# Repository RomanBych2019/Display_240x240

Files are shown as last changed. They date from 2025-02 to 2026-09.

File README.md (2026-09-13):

# Display 240x240

Прошивка дисплея 240x240 для системы CNG/EVO на базе ESP32-C3. Устройство читает данные автомобиля и газового блока по CAN, отображает телеметрию на TFT-дисплее, рассчитывает показатели экономичного вождения и поднимает локальный Wi-Fi веб-портал для просмотра параметров, настройки страниц дисплея, загрузки файлов и OTA-обновления.

## Возможности

- Прием CAN-данных EVO и J1939: обороты, скорость, пробег, расход ДТ, температуры, нагрузка двигателя, вес автомобиля, параметры CNG.
- Отображение страниц на круглом/квадратном TFT 240x240: CNG, параметры EVO, кнопка газ/ДТ, уровень топлива, соленоиды, потеря связи с EVO.
- Переключение пользовательских страниц жестами тач-контроллера CST816D.
- Долгое нажатие на странице кнопки газ/ДТ отправляет CAN-команду включения/выключения газа.
- Расчет уровня экономичного вождения по карте `ACC/RPM`.
- Расчет среднего расхода газа и примерного остаточного пробега.
- Веб-портал в режиме Wi-Fi AP для телеметрии и настроек.
- OTA-обновление через GyverPortal.
- Контроль перегрева ESP32: при высокой температуре снижается мощность Wi-Fi, частота обновления и яркость дисплея.

## Аппаратная платформа

- MCU: `ESP32-C3 DevKitM-1`
- Framework: Arduino
- Дисплей: TFT 240x240, драйвер `GC9A01`, библиотека `TFT_eSPI`
- Тач-контроллер: `CST816D`
- CAN: TWAI ESP32-C3, библиотека `ESP32-TWAI-CAN`
- Файловая система: `LittleFS`

### Основные пины

| Узел | Сигнал | GPIO |
| --- | --- | --- |
| CAN | RX | `GPIO20` |
| CAN | TX | `GPIO21` |
| Touch I2C | SDA | `GPIO4` |
| Touch I2C | SCL | `GPIO5` |
| Touch | INT | `GPIO0` |
| Touch | RST | `GPIO1` |
| TFT SPI | MOSI | `GPIO7` |
| TFT SPI | SCLK | `GPIO6` |
| TFT | CS | `GPIO10` |
| TFT | DC | `GPIO2` |
| TFT | BL | `GPIO3` |
| TFT | RST | `-1` |

Пины TFT задаются в локальной копии библиотеки: `lib/TFT_eSPI-master/User_Setup.h`.

## Сборка и прошивка

Проект собирается через PlatformIO.

```bash
pio run
```

Загрузка прошивки:

```bash
pio run --target upload
```

Загрузка файлов LittleFS из папки `data/`:

```bash
pio run --target uploadfs
```

Монитор порта:

```bash
pio device monitor
```

Основное окружение PlatformIO:

- `env:esp32-c3-devkitm-1`
- `platform = espressif32@5.3.0`
- `board = esp32-c3-devkitm-1`
- `framework = arduino`
- `board_build.partitions = partition.csv`
- `board_build.filesystem = littlefs`
- `monitor_speed = 115200`
- USB CDC включен на старте через `ARDUINO_USB_CDC_ON_BOOT=1`

## Wi-Fi и веб-портал

После запуска устройство поднимает точку доступа:

- SSID: `DisplayEVO`
- Пароль: `00000001`

Веб-портал построен на `GyverPortal`. Через него доступны:

- вкладка телеметрии автомобиля и EVO;
- выбор скорости CAN-шины;
- выбор типа автомобиля;
- настройка объема газовых баллонов;
- включение/отключение страниц дисплея;
- загрузка карты `Map_ACC-RPM.csv`;
- OTA-обновление.

Данные для OTA:

- Логин: `ItalGaz`
- Пароль: `001`

## Файлы LittleFS

Содержимое папки `data/` загружается во flash-файловую систему устройства.

| Файл | Назначение |
| --- | --- |
| `Map_ACC-RPM.csv` | Карта оценки экономичности по педали ACC и RPM |
| `Error_EVO_new.csv` | Справочник ошибок EVO |
| `screen*.png` | PNG-экраны/графика для отображения |
| `display_config.json` | Настройки дисплея и автомобиля, создаются/обновляются прошивкой |

Если `display_config.json` отсутствует, прошивка использует значения по умолчанию из `src/main.cpp` и `src/can_settings.h`.

## CAN-данные

Прошивка принимает расширенные CAN-кадры EVO и стандартные J1939 PGN автомобиля. Основные идентификаторы описаны в `src/can_settings.h`.

### Входящие EVO

| ID | Назначение |
| --- | --- |
| `0x18FFF0BB` | состояние газ/ДТ, ACC, впрыск газа, давление, температуры |
| `0x18FFF1BB` | уровень CNG и температура редуктора |
| `0x18FFFBBB` | ошибки EVO и версия |
| `0x18FFF8BB` | расход газа за поездку и общий расход |
| `0x18FFFAA1` | состояние и токи соленоидов |
| `0x18FFFBA1` | уровень дизельного топлива |

### Входящие J1939

| PGN | Назначение |
| --- | --- |
| `0xFEF1` | скорость автомобиля |
| `0xFEC1` | пробег |
| `0xFEF2` | мгновенный расход ДТ |
| `0xF004` | обороты и нагрузка двигателя |
| `0xFEF6` | температуры воздуха/выхлопа |
| `0xFEEE` | температуры ОЖ, масла, топлива |
| `0xFEEA` | вес автомобиля |

### Исходящие CAN

| ID | Назначение |
| --- | --- |
| `0x18FFEEDD` | команда включения/выключения газа |
| `0x18FFFEDD` | диагностические данные дисплея: экономичность, средний расход, запас хода, объем баллонов |

## Структура проекта

```text
.
├── data/                  # файлы LittleFS
├── display/               # графические исходники дисплея
├── docs/                  # документация, схемы, платы, даташиты
├── include/               # стандартная папка PlatformIO
├── lib/                   # локальные библиотеки проекта
├── src/                   # исходный код прошивки
├── test/                  # стандартная папка PlatformIO
├── platformio.ini         # настройки сборки
├── partition.csv          # разметка flash
├── max_app_4MB.csv        # альтернативная разметка
└── min_spiffs.csv         # альтернативная разметка
```

Ключевые файлы в `src/`:

- `main.cpp`, `main.h` - запуск, задачи FreeRTOS, обработка CAN, расчеты, LittleFS-настройки.
- `TFT_240_240.cpp`, `TFT_240_240.h` - отрисовка страниц TFT-дисплея.
- `WebPortal.cpp`, `WebPortal.h` - Wi-Fi AP, веб-интерфейс, OTA, загрузка файлов.
- `CST816D.cpp`, `CST816D.h` - работа с тач-контроллером.
- `can_settings.h` - структура CAN-данных и PGN/ID.
- `DisplayConfig.h` - описание страниц дисплея.
- `PNG_FS_Support.cpp`, `PNG_FS_Support.h` - вывод PNG из файловой системы.
- `SolenoidHealth.h` - состояния соленоидов.

## Локальные библиотеки

В проекте используются локальные копии библиотек:

- `lib/TFT_eSPI-master`
- `lib/PNGdec-master`
- `lib/ESP32-TWAI-CAN-master`

Также через `platformio.ini` подтягиваются:

- `gyverlibs/GyverPortal@^3.6.6`
- `bblanchon/ArduinoJson`

## Настройка страниц дисплея

Начальная конфигурация страниц задается в `src/main.cpp` в объекте `g_displayConfig`.

Доступные страницы:

- `CNG`
- `Параметры EVO`
- `Кнопка газ/дт`
- `Уровень топлива`
- `Соленоиды`
- `EVO Lost`

Веб-портал может включать и отключать пользовательские страницы. Системная страница `EVO Lost` используется для индикации потери связи с газовым блоком.

## Документация

Папка `docs/` содержит схемы, KiCad-проект платы, даташиты и инструкции. Наиболее полезные материалы:

- `docs/Инструкция.pdf`
- `docs/Инструкция карты.pdf`
- `docs/KiCad - TTF 240х240/`
- `docs/SPEC LH128R-IG01 VER A.pdf`
- `docs/esp32-c3_datasheet_en.pdf`

## Примечания для разработки

- Перед проверкой работы на устройстве прошивайте и firmware, и LittleFS.
- При изменении пинов дисплея правьте `lib/TFT_eSPI-master/User_Setup.h`.
- При изменении формата CAN-данных сначала обновляйте `src/can_settings.h`, затем парсинг в `analise_can_id()`.
- Для настройки жестов не удаляйте лог `Touch: x=..., y=..., gesture=...` в `src/main.cpp`: он нужен для проверки координат и распознавания жестов.
- В репозитории есть `.DS_Store` и `Thumbs.db`; они не нужны для сборки.

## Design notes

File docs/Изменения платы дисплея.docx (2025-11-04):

Измения на плату дисплея 240х240 dpi

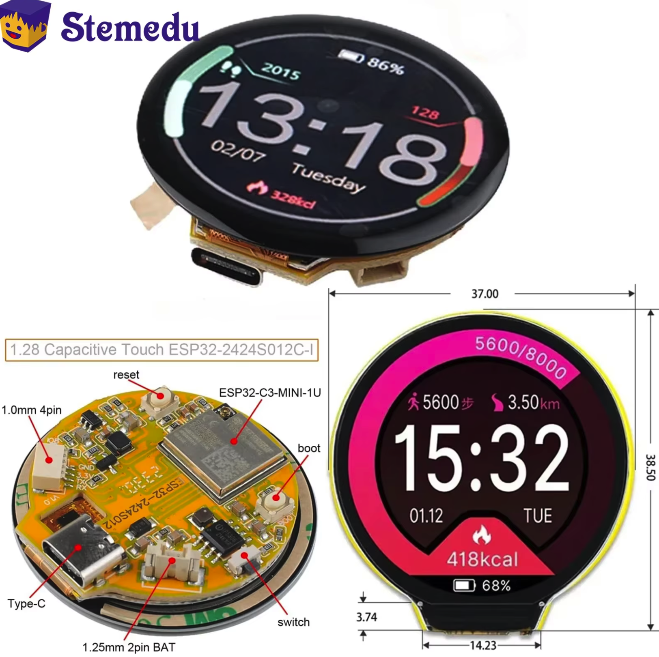
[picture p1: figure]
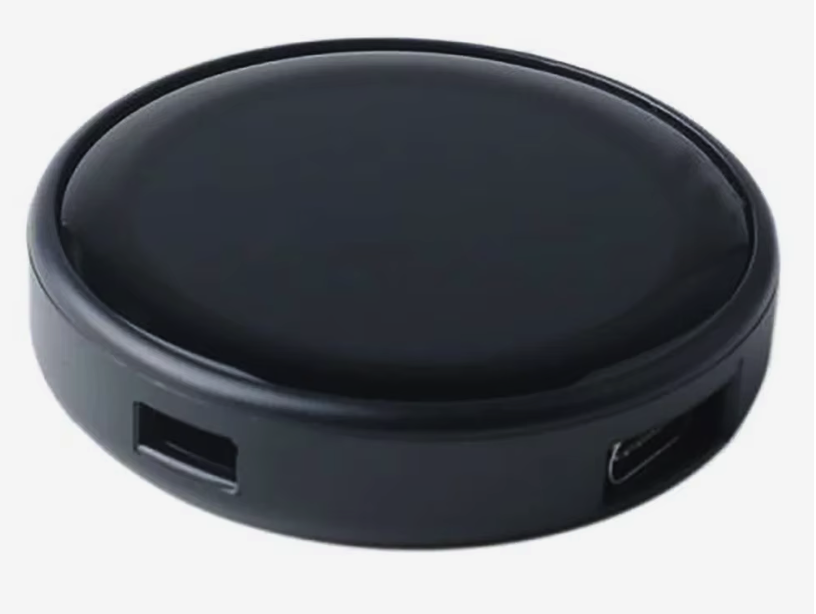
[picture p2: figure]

Производитель - http://www.jczn1688.com

Для нашего изделия необходимо переделка платы

1. Удаление разъема TypeC, разъема 4pin, разъема 2pin BAT, переключателя switch, микросхемы зарядки аккумулятора.

2. Добавить микросхему TJA1050, разъем 4pin 1.25, 4 контактные площадки

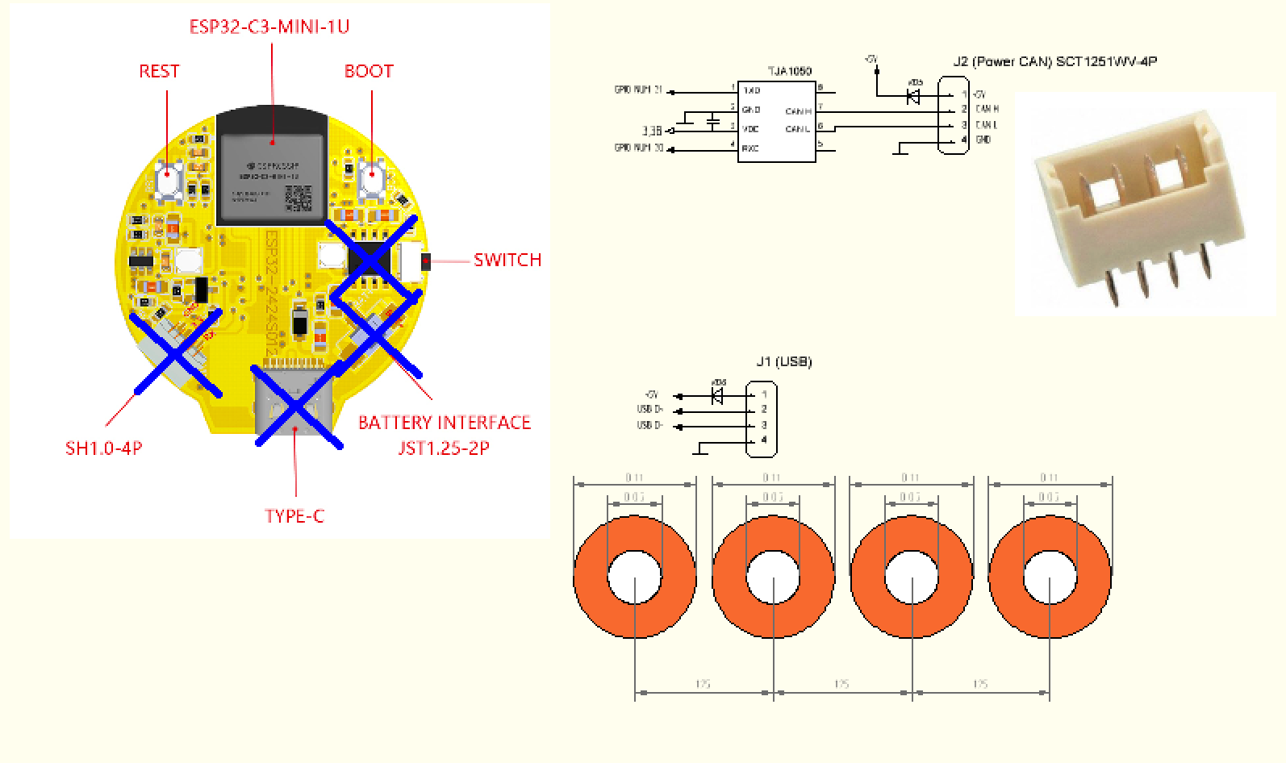
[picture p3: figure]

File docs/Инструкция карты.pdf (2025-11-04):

## Карта для вычисления оценки экономичности вождения и оставшегося пробега на газовом топливе

Файл настроек предназначен для корректной работы дисплея -вычисления оценки экономичности вождения (по карте ACC-RPM), вычисления оставшегося пробега на газовом топливе (значение TankVolume).

Этот файл может быть различным как для разных моделей автомобилей, так и для одинаковых моделей, но с разными объемами газовых баллонов (например, машина оснащена прицепом с газовыми баллонами).

Неверная информация об объеме газовых баллонов приводит к неверному вычислению оставшегося пробега, неверная карта ACC-RPM приводит к неверному вычислению оценки качества вождения.

Неверная информация в поле TypeCan может привести к некорректной работе дисплея - невозможности вычисления оценки качества вождения и/или оставшегося пробега.

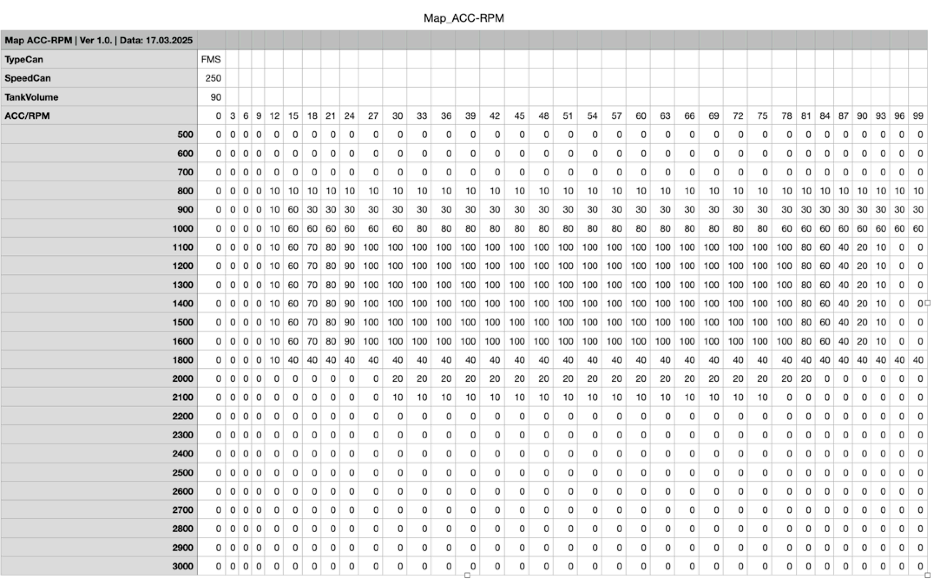
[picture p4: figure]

Формат файла - csv, разделители запятая

Строки:

1 - Информация о карте - версия, дата создания (текстовый формат)

2 - TypeCan - версия данных в кан-шине. Возможно для некоторых машин придется делать свои версии, тогда здесь будет идентификатор конкретной версии автомобиля. Пока просто FMS.

3 - SpeedCan - скорость кан-шины. Сейчас дисплей сам определяет скорость из диапазона 125-666 кБ. Но если заранее известна скорость, лучшее ее записать.

4 - TankVolume - объем газовых баллонов, м3. Эта величина используется для расчета запаса хода.

5 и до конца файла - таблица экономичности вождения. Строки - обороты двигателя (данные из кан-шины автомобиля), столбцы - процент нажатия на педаль акселератора (данные из кан шины газового блока EVO PLUS NEW), значения в ячейках - уровень экономичности от 0 до 100, 100 -максимальная экономичность. Дисплей отображает красным цветом значения от 0 до 40, желтым - от 40 до 70, зеленым - от 70 до 100.

## Запись и редактирование карты

1. Подключиться к wi-fi сети DisplayEVO (пароль 00000001)
2. Зайти в браузере на web страницу по адресу 192.168.4.1

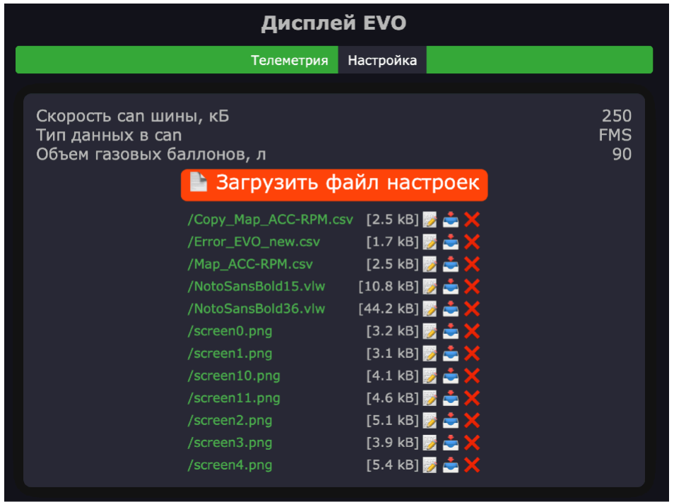
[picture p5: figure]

3. Выбрать вкладку «Настройка»
4. Нажать кнопку «Загрузить файл настроек»
5. Выбрать необходимый файл
6. После загрузки выключить зажигание. После включения зажигания вновь подключиться к дисплею, зайти в «Настройки», проверить корректность настроек «Скорость can шины», «Тип данных в can» и «Объем газовых баллонов».
7. Пока можно и скачать ранее записанный файл, нажав значок напротив строки /Map_ACC-RPM.csv
8. Редактировать карту можно в экселе, сохранения только в формате csv с разделителями запятые. Если будет записан неверный формат, дисплей сотрет этот новый файл и восстановит копию из своей памяти. Если файл по формальным признакам будет корректным, дисплей перезапишут копию в своей памяти. Разметку карты менять нельзя.
9. После редактирования новый файл можно записать в дисплей.

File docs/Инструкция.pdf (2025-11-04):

# Общая информация

Дисплей предназначен для ввода информации о работе газовой системы на основе блока управления EVO PLUS NEW, а так же информировать водителя о стиле вождения для максимальной экономии дизельного топлива.

Дисплей оснащен емкостям сенсором, позволяющим переключать экраны отображаемой информации, а так же управлять включением газового блока.

Переключение между экранами происходит «свайпом» сверху-вниз или снизу-вверх.

Управление включением газового блока происходит долгим касанием соответствующего символа.

Для корректной работы дисплея необходимо загрузить корректный файл с настройками и картой экономичного вождения. Карта создается для каждого типа автомобиля после калибровочных поездок и создания газовых карт для этого типа автомобиля.

# Экран переключение режима газ/ дизель

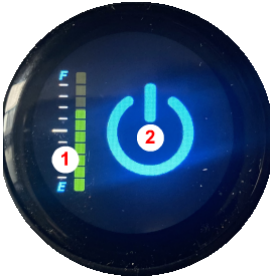
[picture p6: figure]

1 - объем газового топлива в баллонах, %

2 - область включения/отключения режима газ-дизель. Значок синего цвета - активирован режим газ-дизель. Значок белого цвета - газовая система отключена.

Для переключения режимов необходимо длительное (5 секунд) касание экрана в области 2. После переключения режима работы газовой системы экран в течении 10 секунд не реагирует на касания.

Экран включения/отключения режима газ-дизель

# Экран параметры газового блока EVO

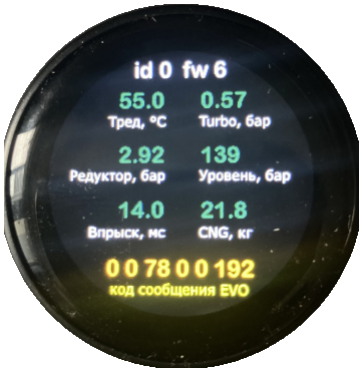
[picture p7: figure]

id\fw - номер прошивки в блоке EVO

Тред - температура редуктора, С

Turbo - давление турбонагнетателя, бар

Редуктор - давление газа после редуктора, бар

Уровень - давление газа в баллонах, бар

Впрыск - время впрыска газа, мсек

CNG - мгновенный расход газа, кг

код сообщения EVO - цифровой код сообщения блока EVO с флагами ошибок и состояний

Экран вывода параметров EVO

# Экран экономайзер

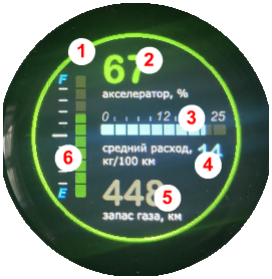
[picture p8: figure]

1 - индикация стиля вождения с точки зрения экономии дизельного топлива: красный цвет - неэкономичный режим, желтый цвет - средний режим, зеленый цвет - экономичный режим. В режиме дизель индикация стиля вождения не выводится на дисплей

2 - уровень нажатия на педаль акселератора. Цвет надписи соответствует цвету п.1. При переключении в режим дизель цвет надписи - серый

3 - шкала мгновенного расхода газа, кг

4 - средний расход газа, кг/100 км. Средний расход высчитывается по формуле расход газа/пробег, расчет и вывод на дисплей начинается после пробега в режиме га-дизель 1 км.

5 - запас хода на газовом топливе, км. Рассчитывается исходя из среднего расхода газа, объема баллонов из файла конфигурации и давления газа в баллонах. При переключении в режим дизель выводится надпись Disel

6 - объем газового топлива в баллонах, %

Экран вывода параметров расхода газового топлива

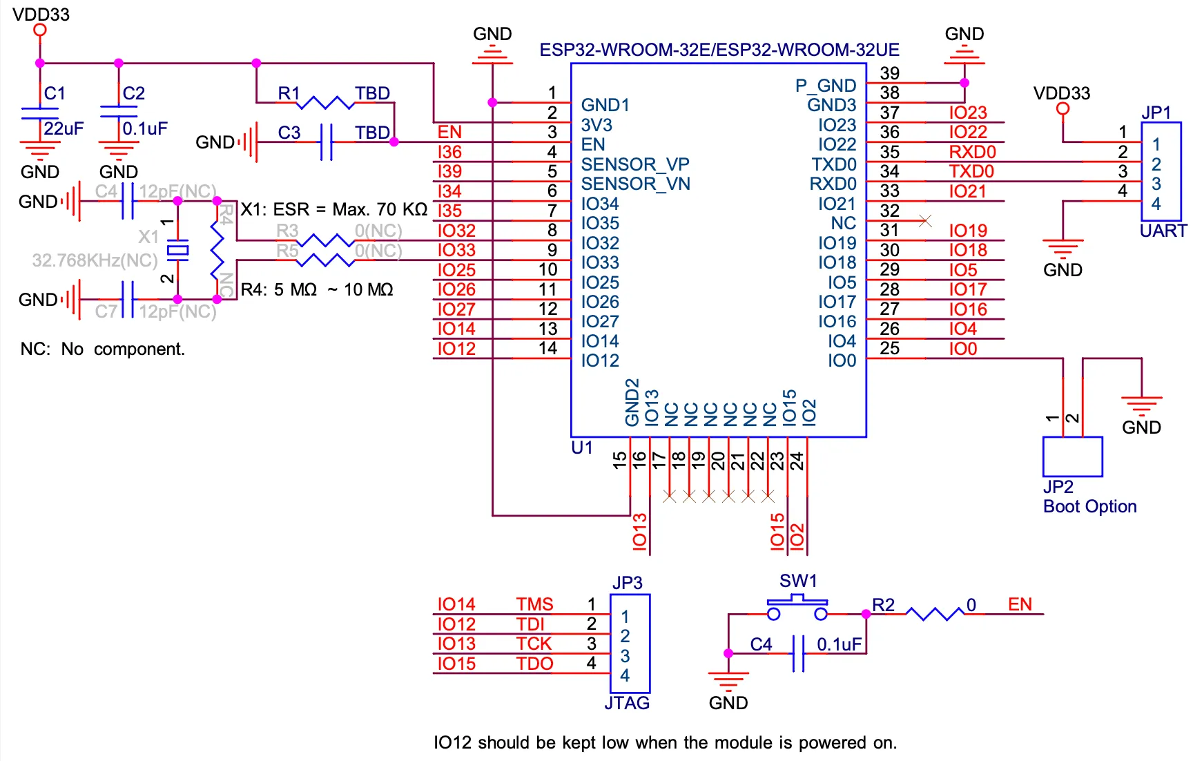
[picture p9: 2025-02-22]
docs/esp32_obvyazka.CPLEmjY2_Z1Jyuov.webp

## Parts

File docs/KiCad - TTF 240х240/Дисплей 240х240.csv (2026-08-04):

Reference | Qty | Value | Описание
C1,C3,C5,C8,C11 | 5 | 0.1µF | AC0603KRX7R9BB104
C2 | 1 | 10µF 50v | C3216X7R1H106K160AC
C4 | 1 | 4.7nF | Unpolarized capacitor
C6,C7 | 2 | 10µF10v | GRM21BR61A106KE
D1,D8 | 2 | BAV70 | Dual 100V 215mA high-speed switching diodes, common cathode, SOT-23
D2 | 1 | SMAJ30A | 400W unidirectional Transient Voltage Suppressor, 24.0Vr, SMA(DO-214AC)
D4 | 1 | SM712_SOT23 | 7V/12V, 600W Asymmetrical TVS Diode Array, SOT-23
D5 | 1 | ESDA25W | TVS Diode Array, 5.5V Standoff, 2 Channels, SOT23
J1 | 1 | Display | Generic connector, single row, 01x16, script generated
J2 | 1 | USB | Generic connector, single row, 01x04, script generated (kicad-library-utils/schlib/autogen/connector/)
J3 | 1 | Input | Generic connector, single row, 01x04, script generated (kicad-library-utils/schlib/autogen/connector/)
L2 | 1 | 4.7µH | LQH44PN2R2MPOL
Q1 | 1 | AO3402 | N-MOSFET transistor, gate/source/drain
R1 | 1 | 1 | Resistor
R2,R4,R6,R11,R17,R18,R19 | 7 | 10k | Resistor
R3,R5 | 2 | 60 | AC0603FR-0760R4L
R7 | 1 | 120 | Resistor
R8 | 1 | 68k | Resistor
R9 | 1 | 22k | Resistor
R15,R16 | 2 | 4.7k | Resistor
R20 | 1 | 3.9 | Resistor
SW1 | 1 | reset | Push button switch, generic, two pins
SW2 | 1 | boot | Push button switch, generic, two pins
U1 | 1 | SN65HVD230 | CAN Bus Transceivers, 3.3V, 1Mbps, Low-Power capabilities, SOIC-8
U2 | 1 | THVD1406D | Half duplex RS-485/RS-422, 500 Kbps, 3V - 5.5V supply, ±12kV electro-static discharge (ESD) protection, with receiver/driver enable, 32 receiver drive capacity, SOIC-8
U3 | 1 | LMR50410 | 1.2 A Simple Buck Regulator, 3-26V input, 1.5Mhz
U5 | 1 | ESP32-C3-MINI-1U | ESP32-C3-MINI-1 family is an ultra-low-power MCU-based SoC solution that supports 2.4 GHz Wi-Fi and Bluetooth®Low Energy (Bluetooth LE).
U7 | 1 | AP2112K-3.3 | 600mA low dropout linear regulator, with enable pin, 3.8V-6V input voltage range, 3.3V fixed positive output, SOT-23-5

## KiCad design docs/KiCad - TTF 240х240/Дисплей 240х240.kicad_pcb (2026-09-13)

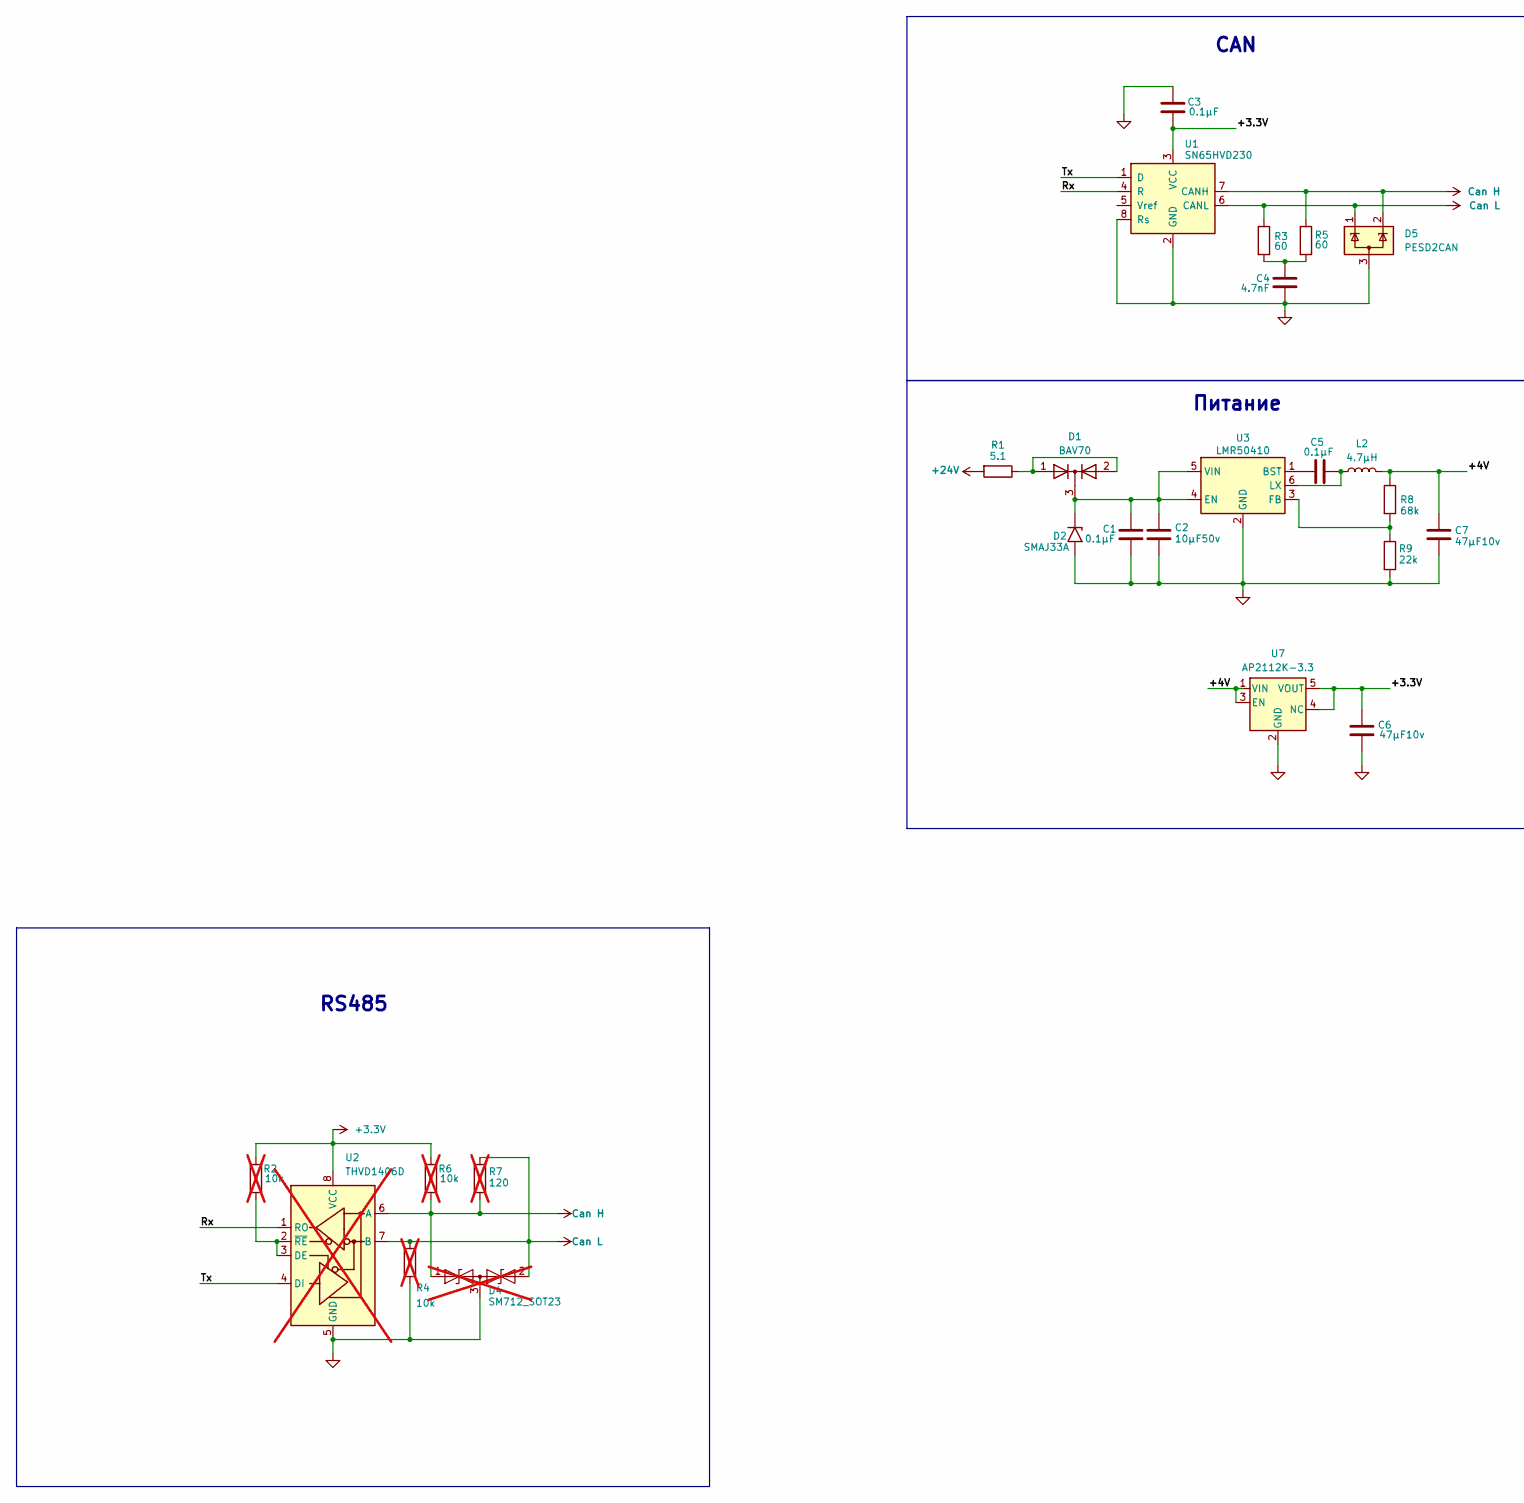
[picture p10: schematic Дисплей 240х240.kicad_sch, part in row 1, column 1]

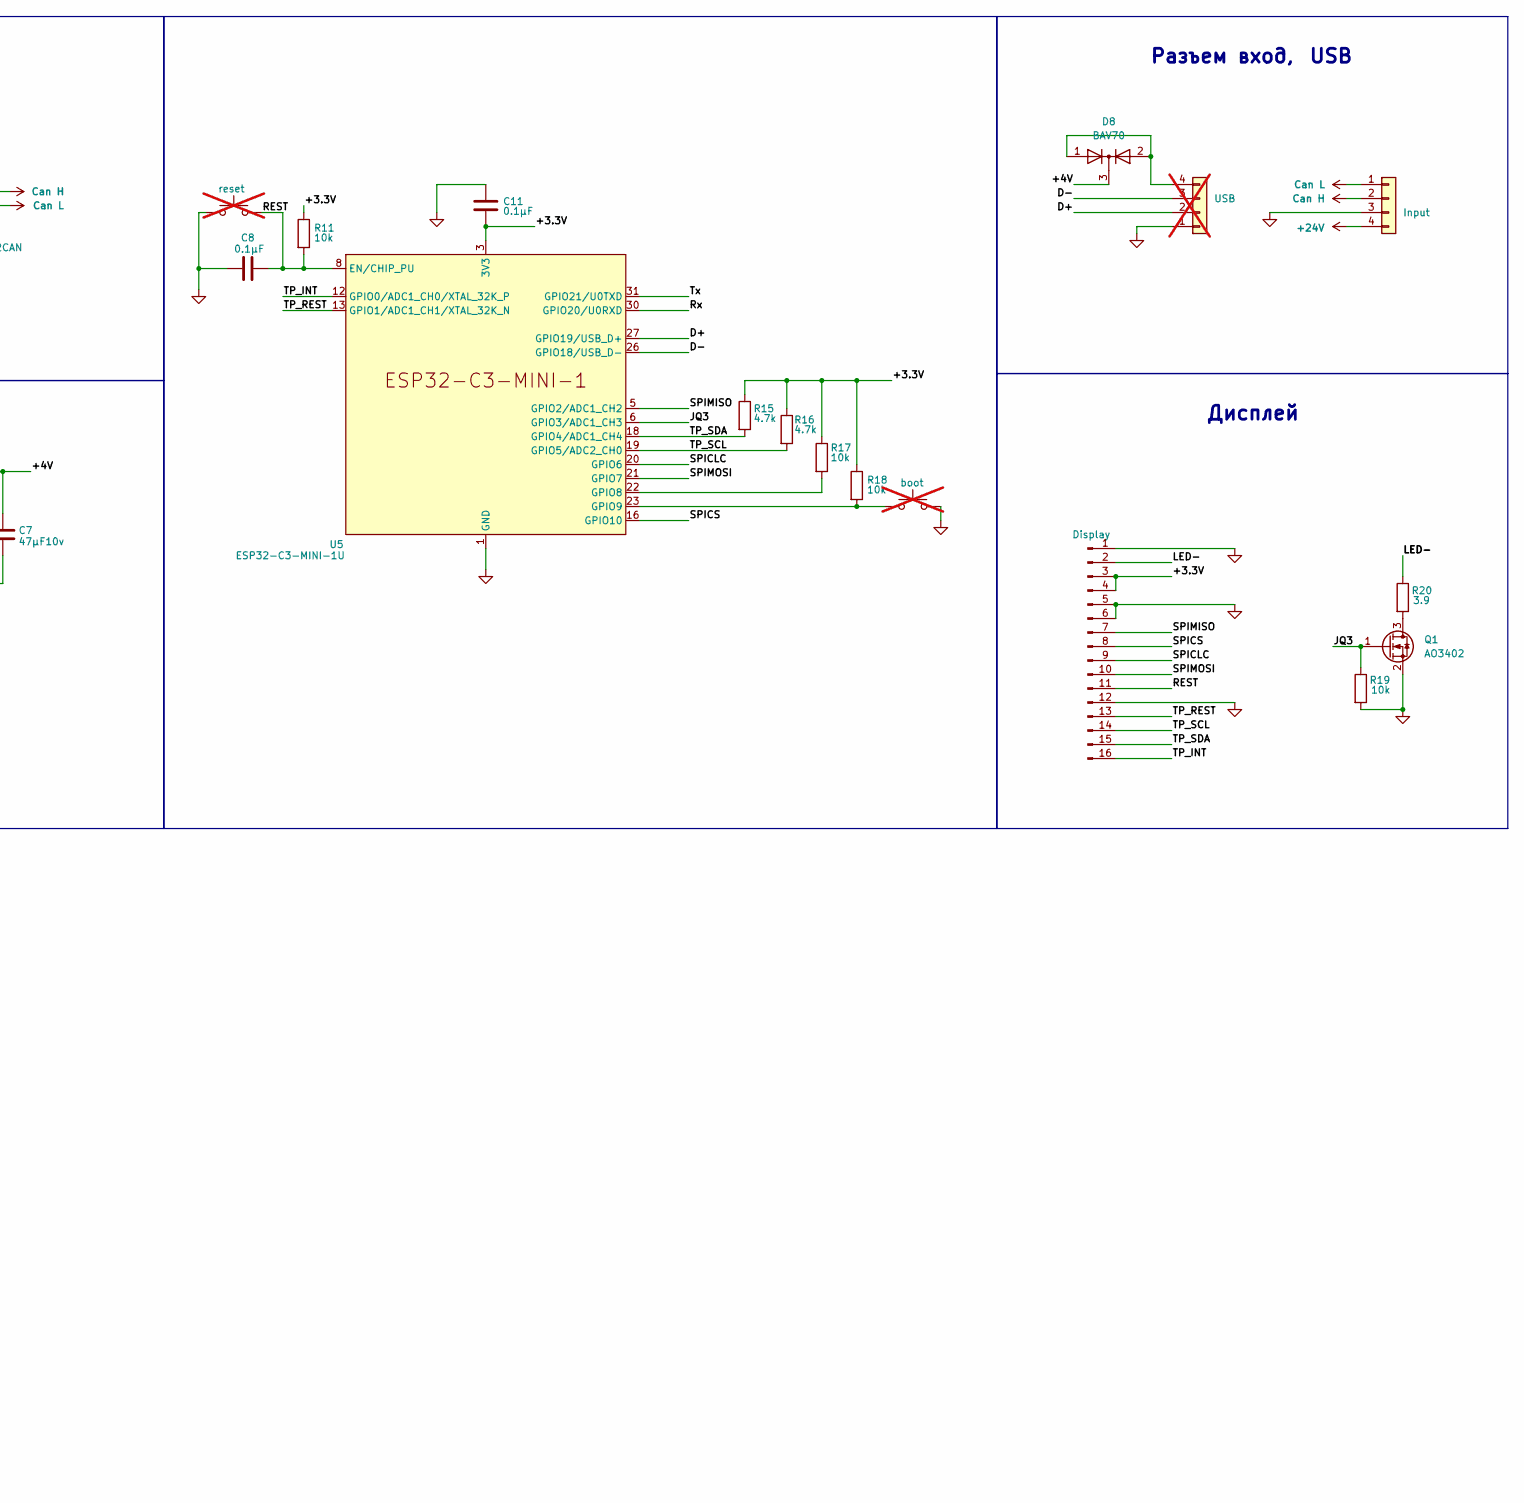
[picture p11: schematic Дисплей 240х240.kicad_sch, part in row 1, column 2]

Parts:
C1, C3, C5, C8, C11: 0.1µF; C_0603_1608Metric
C2: 10µF50v; C_0805_2012Metric
C4: 4.7nF; C_0603_1608Metric
C6, C7: 47µF10v; C_0805_2012Metric
D1, D8: BAV70; SOT-23
D2: SMAJ33A; D_SMA
D4: SM712_SOT23; SOT-23; not fitted
D5: PESD2CAN; SOT-23
J1: Display; ER-OLED0.42
J2: USB; PinHeader_1x04_P2.54mm_Vertical; not fitted
J3: Input; JST_GH_BM04B-GHS-TBT_1x04-1MP_P1.25mm_Vertical
L2: 4.7µH; L_1210_3225Metric
Q1: AO3402; SOT-23
R1: 5.1; R_0805_2012Metric
R2, R4, R6: 10k; R_0603_1608Metric; not fitted
R3, R5: 60; R_0603_1608Metric
R7: 120; R_0603_1608Metric; not fitted
R8: 68k; R_0603_1608Metric
R9: 22k; R_0603_1608Metric
R11, R17, R18, R19: 10k; R_0603_1608Metric
R15, R16: 4.7k; R_0603_1608Metric
R20: 3.9; R_0603_1608Metric
SW1: reset; SW_SPST_B3U-1000P; not fitted
SW2: boot; SW_SPST_B3U-1000P; not fitted
U1: SN65HVD230; SOIC-8_3.9x4.9mm_P1.27mm
U2: THVD1406D; SOIC-8_3.9x4.9mm_P1.27mm; not fitted
U3: LMR50410; SOT-23-6
U5: ESP32-C3-MINI-1U
U7: AP2112K-3.3; SOT-23-5

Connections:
+3.3V: C3.1, C6.1, C11.1, J1.3, J1.4, R2.1, R6.1, R11.1, R15.1, R16.1, R17.1, R18.1, U1.3 (VCC), U2.8 (VCC), U5.3 (3V3), U7.4 (NC), U7.5 (VOUT)
+24V: J3.4, R1.2
/+4V: C7.1, D8.3 (K), L2.2, R8.1, U7.1 (VIN), U7.3 (EN)
/<NO NET>: U1.1 (D), U1.4 (R), U2.1 (RO), U2.4 (DI), U5.30 (GPIO20/U0RXD), U5.31 (GPIO21/U0TXD)
/D+: J2.2, U5.27 (GPIO19/USB_D+)
/D-: J2.3, U5.26 (GPIO18/USB_D-)
/JQ3: Q1.1 (G), R19.1, U5.6 (GPIO3/ADC1_CH3)
/LED-: J1.2, R20.1
/REST: C8.1, J1.11, R11.2, SW1.2, U5.8 (EN/CHIP_PU)
/SPICLC: J1.9, U5.20 (GPIO6)
/SPICS: J1.8, U5.16 (GPIO10)
/SPIMISO: J1.7, U5.5 (GPIO2/ADC1_CH2)
/SPIMOSI: J1.10, U5.21 (GPIO7)
/TP_INT: J1.16, U5.12 (GPIO0/ADC1_CH0/XTAL_32K_P)
/TP_REST: J1.13, U5.13 (GPIO1/ADC1_CH1/XTAL_32K_N)
/TP_SCL: J1.14, R16.2, U5.19 (GPIO5/ADC2_CH0)
/TP_SDA: J1.15, R15.2, U5.18 (GPIO4/ADC1_CH4)
Can H: D4.1 (A1), D5.2 (K), J3.2, R5.1, R6.2, R7.2, U1.7 (CANH), U2.6 (A)
Can L: D4.2 (A2), D5.1 (K), J3.1, R3.1, R4.1, R7.1, U1.6 (CANL), U2.7 (B)
GND: C1.2, C2.2, C3.2, C4.1, C6.2, C7.2, C8.2, C11.2, D2.2 (A2), D4.3 (common), D5.3 (A), J1.1, J1.5, J1.6, J1.12, J2.1, J3.3, Q1.2 (S), R4.2, R9.2, R19.2, SW1.1, SW2.2, U1.2 (GND), U1.8 (Rs), U2.5 (GND), U3.2 (GND), U5.1 (GND), U5.2 (GND), U5.11 (GND), U5.14 (GND), U5.36 (GND), U5.37 (GND), U5.38 (GND), U5.39 (GND), U5.40 (GND), U5.41 (GND), U5.42 (GND), U5.43 (GND), U5.44 (GND), U5.45 (GND), U5.46 (GND), U5.47 (GND), U5.48 (GND), U5.49 (GND), U5.50 (GND), U5.51 (GND), U5.52 (GND), U5.53 (GND), U7.2 (GND)
unnamed: C4.2, R3.2, R5.2
unnamed: D1.1 (A), D1.2 (A), R1.1
unnamed: C1.1, C2.1, D1.3 (K), D2.1 (A1), U3.4 (EN), U3.5 (VIN)
unnamed: D8.1 (A), D8.2 (A), J2.4
unnamed: Q1.3 (D), R20.2
unnamed: R2.2, U2.2 (~RE), U2.3 (DE)
unnamed: C5.2, U3.1 (BST)
unnamed: R8.2, R9.1, U3.3 (FB)
unnamed: C5.1, L2.1, U3.6 (LX)
unnamed: R17.2, U5.22 (GPIO8)
unnamed: R18.2, SW2.1, U5.23 (GPIO9)

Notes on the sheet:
Питание
Дисплей
CAN
RS485
Разъем вход, USB

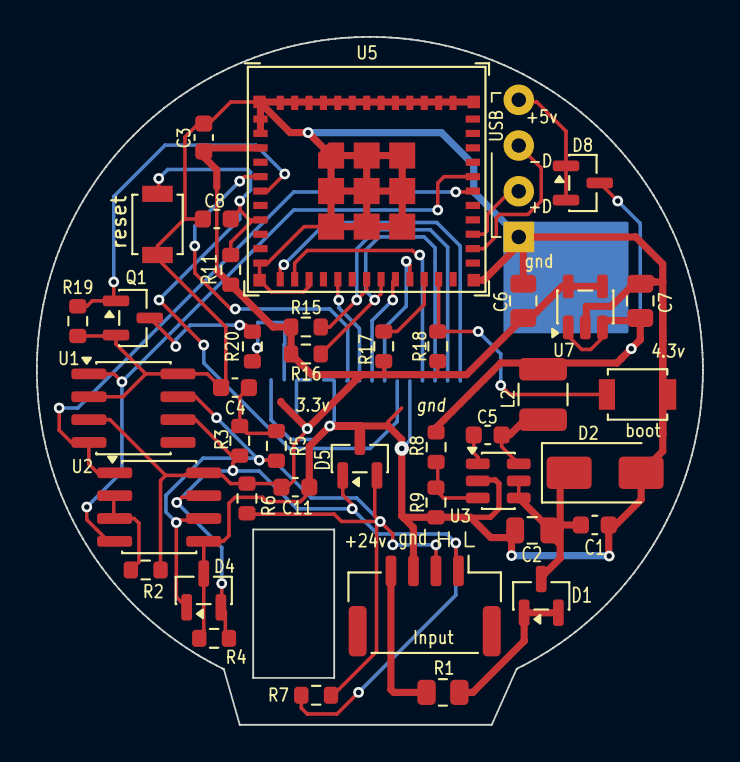
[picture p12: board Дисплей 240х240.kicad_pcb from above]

Board: 2 copper layers, 37.0 x 38.2 mm, 42 parts (1 on the bottom side), 31 nets.

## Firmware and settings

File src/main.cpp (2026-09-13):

#include "main.h"
#include "WebPortal.h"
#include <map>
#include <ArduinoJson.h>

#include "DisplayConfig.h"
#include "esp_wifi.h"

DisplayConfig g_displayConfig = {
    .pages = {
        {DisplayPageId::CNG, "cng", "CNG", true, 1, false},
        {DisplayPageId::ParamEVO, "paramEvo", "Параметры EVO", true, 0, false},
        {DisplayPageId::ButtonOn, "button", "Кнопка газ/дт", true, 2, false},
        {DisplayPageId::LSLevel, "lls", "Уровень топлива", false, 3, false},
        {DisplayPageId::ValveTank, "valve", "Соленоиды", true, 4, false},
        {DisplayPageId::EVOLost, "evoLost", "EVO Lost", true, 255, true},
    }};

void setup(void)
{
  Serial.begin(115200);
  delay(1000);


  if (!LittleFS.begin(FORMAT_LITTLEFS_IF_FAILED))
  {
    log_e("LittleFS mount failed");
  }

  maindisplay = new TFT_240_240();
  touch.begin();

  loadAccRpmFile(map_ACC_RPM, MAP_ACC_RPM_NAME); //  загрузка карты ACC\RPM
  errorStringtoVec(error_evo);                   //  загрузка списка ошибок газового блока EVO из внешнего файла
  loadDisplayConfig();                           //  загрузка настроек дисплея из json файла
  maindisplay->setDisplayConfig(g_displayConfig);

  ESP32Can.twaiGenerateFilter(0x1CFFFFFF, 0x18000000, true);
  ESP32Can.begin(ESP32Can.convertSpeed(data_can.canSpeed), CAN_TX, CAN_RX, 10, 10);
  g_displayQueue = xQueueCreate(8, sizeof(DisplayMessage));
  if (g_displayQueue == nullptr)
  {
    log_e("display queue create failed");
    while (1)
      yield();
  }

  xTaskCreate(
      uiTick,        /* Обновление  */
      "Task_uiTick", /* Название задачи */
      4096,          /* Размер стека задачи */
      NULL,          /* Параметр задачи */
      1,             /* Приоритет задачи */
      NULL);         /* Идентификатор задачи, чтобы ее можно было отслеживать *);            /* Ядро для выполнения задачи (1) */

  xTaskCreate(
      send_CAN,       /* Обновление  */
      "Task_sendCAN", /* Название задачи */
      4096,           /* Размер стека задачи */
      NULL,           /* Параметр задачи */
      0,              /* Приоритет задачи */
      NULL);          /* Идентификатор задачи, чтобы ее можно было отслеживать */

  xTaskCreate(
      watch_dog_CAN,        /* Обновление  */
      "Task_watch_dog_CAN", /* Название задачи */
      2048,                 /* Размер стека задачи */
      NULL,                 /* Параметр задачи */
      10,                   /* Приоритет задачи */
      NULL);                /* Идентификатор задачи, чтобы ее можно было отслеживать */

  xTaskCreate(
      taskDisplay,
      "taskDisplay",
      4096,
      nullptr,
      3,
      nullptr);

  xTaskCreate(
      taskupdateThermalState,
      "taskupdateThermalState",
      2048,
      nullptr,
      10,
      nullptr);

  if (g_displayQueue)
  {
    DisplayMessage msg{};
    msg.type = DisplayCmdType::NextPage;
    xQueueSend(g_displayQueue, &msg, 0);
  }
    Serial.println("Setup complit");
    time_touch = 0;

  webPortal.begin();
}

void loop()
{
  webPortal.tick();

  Can_Data dataSnap = snapshotDataCan();

  if (counter_lost_can_vehicle > TIME_LOST_CAN) //  если нет данных по кан более TIME_LOST_CAN секунд вешаем флаг ошибки
  {
    portENTER_CRITICAL(&dataMux);
    can_ok = false;
    portEXIT_CRITICAL(&dataMux);
  }

  if (ESP32Can.readFrame(rxFrame, 100))
  {
    portENTER_CRITICAL(&dataMux);
    can_ok = true;
    portEXIT_CRITICAL(&dataMux);

    analise_can_id(rxFrame);

    if (g_displayQueue)
    {
      DisplayMessage msg{};
      msg.type = DisplayCmdType::UpdateData;
      msg.data = data_can;
      xQueueSend(g_displayQueue, &msg, 0); // только если очередь длиной 1}
    }
  }

  if (millis() > time_touch)
  {
    if (touch.getTouch(&touchX, &touchY, &gesture))
    {
      log_e("Touch: x=%d, y=%d, gesture=%d", touchX, touchY, gesture); // не удалять вывод жестов, он нужен для настройки координат и распознавания жестов на дисплее
      switch (gesture)
      {
      case GESTURE::SlideDown:
        if (g_displayQueue)
        {
          DisplayMessage msg{};
          msg.type = DisplayCmdType::NextPage;
          xQueueSend(g_displayQueue, &msg, 0);
        }
        time_touch = millis() + PAUSE_TOUCH_ON;
        break;
      case GESTURE::SlideUp:
        if (g_displayQueue)
        {
          DisplayMessage msg{};
          msg.type = DisplayCmdType::PrevPage;
          xQueueSend(g_displayQueue, &msg, 0);
        }
        time_touch = millis() + PAUSE_TOUCH_ON;
        break;
      case GESTURE::LongPress:
        if ((maindisplay->getScreenNowShow() == static_cast<int>(DisplayPageId::ButtonOn)) && ((touchX > 30 && touchX < 210) && (touchY > 30 && touchY < 210)))
        {
          bool localGasOn;
          bool localCanOk;
          portENTER_CRITICAL(&dataMux);
          gas_on = !gas_on;
          localGasOn = gas_on;
          localCanOk = can_ok;
          portEXIT_CRITICAL(&dataMux);
          time_touch = millis() + 20 * PAUSE_TOUCH_ON;
          if (localCanOk && millis() > 10000)
          {
            uint8_t payload[8] = {0};
            payload[0] = localGasOn ? 1 : 0;
            // Serial.println("Send CAN");
            sendCanFrame(PGN_SEND_ON_EVO, payload, 8, 100);
          }
        }
        break;
      default:
        break;
      }
    }
  }
}

/*
    анализ входящего CAN сообщения, обновление данных в структуре data_can
    и состояния клапанов баллонов в массиве valves на основе данных из КАН шины
*/
void analise_can_id(CanFrame &frame)
{
  unsigned long PGN_32 = frame.identifier;
  int maxVolumeOil {};
  int maxVolumeLLS {};
  int llsValue {};

  portENTER_CRITICAL(&dataMux);
  switch (PGN_32)
  {
  case PGN1:
    data_can.state = frame.data[0];
    gas_on = frame.data[0];
    data_can.cngDieselReduction = frame.data[1];
    data_can.ACC = frame.data[4];
    data_can.cngInjectionTime = frame.data[2] / 10.f;
    data_can.cngTurboPressure = frame.data[3] / 100.0f;
    data_can.cngRailPressure = frame.data[5] / 50.f;
    data_can.cngRailTemperature = frame.data[6] - 40;
    data_can.exhaustGasTemper = frame.data[7] * 5;
    counter_lost_can_EVO = 0;
    break;

  case PGN2:
    data_can.cngLevel = frame.data[6];
    data_can.cngWaterTemperature = frame.data[7];
    counter_lost_can_EVO = 0;
    break;

  case PGN3:
    data_can.errorEVO[0] = frame.data[0];
    data_can.errorEVO[1] = frame.data[1];
    data_can.errorEVO[2] = frame.data[2];
    data_can.errorEVO[3] = frame.data[3];
    data_can.errorEVO[4] = frame.data[4];
    data_can.errorEVO[5] = frame.data[5];
    data_can.verID = frame.data[6];
    data_can.verFMlow = frame.data[7];
    data_can.cruise = frame.data[3] & B00000001;
    counter_lost_can_EVO = 0;
    break;

  case PGN4:
    data_can.cngIstValue = frame.data[3] / 10.0f;
    data_can.cngTripFuel = (frame.data[0] | frame.data[1] << 8 | frame.data[2] << 16) / 1000.0f;
    data_can.cngTotalFuelUsed = (frame.data[4] | frame.data[5] << 8 | frame.data[6] << 16 | frame.data[7] << 24) / 2.0f;
    counter_lost_can_EVO = 0;
    break;

  case PGN13:
    valves[0].updateState(static_cast<SolenoidHealth>(frame.data[6] & B00000111), frame.data[2], frame.data[1] & B00000001);
    valves[1].updateState(static_cast<SolenoidHealth>((frame.data[6] >> 4) & B00000111), frame.data[3], (frame.data[1] & B00000010) >> 1);
    valves[2].updateState(static_cast<SolenoidHealth>((frame.data[7]) & B00000111), frame.data[4], (frame.data[1] & B00000100) >> 2);
    valves[3].updateState(static_cast<SolenoidHealth>((frame.data[7] >> 4) & B00000111), frame.data[5], (frame.data[1] & B00001000) >> 3);
    break;

  case PGN14:
    data_can.full_tank = frame.data[2] | frame.data[3] << 8;
    maxVolumeOil = frame.data[6] | frame.data[7] << 8;
    maxVolumeLLS = frame.data[4] | frame.data[5] << 8;
    llsValue = frame.data[0] | frame.data[1] << 8;
    data_can.lls = lls_tarring(llsValue, maxVolumeOil, maxVolumeLLS);
    // log_e("LLS: %d, maxVolumeOil: %d, maxVolumeLLS: %d", llsValue, maxVolumeOil, maxVolumeLLS);
    break;

  default:
    break;
  }

  uint16_t PGN = (uint16_t)(PGN_32 >> 8);
  switch (PGN)
  {
  case PGN5:
    data_can.wheelSpeed = (frame.data[1] | frame.data[2] << 8) / 256.0f;
    counter_lost_can_vehicle = 0;
    break;

  case PGN6:
    data_can.distance = (frame.data[0] | frame.data[1] << 8 | frame.data[2] << 16 | frame.data[3] << 24) / 200.0f;
    counter_lost_can_vehicle = 0;
    break;

  case PGN7:
    data_can.oilFuelRate = (frame.data[0] | frame.data[1] << 8) / 20.0f;
    counter_lost_can_vehicle = 0;
    break;

  case PGN8:
    data_can.rpm = (frame.data[3] | frame.data[4] << 8) / 8.0;
    data_can.engineLoad = frame.data[2] - 125;
    counter_lost_can_vehicle = 0;
    break;

  case PGN10:
    counter_lost_can_vehicle = 0;
    break;

  case PGN11:
    data_can.engineTemper = frame.data[0] - 40;
    data_can.fuelTemper = frame.data[1] - 40;
    data_can.oilTemper = (frame.data[2] | frame.data[3] << 8) * 0.03125 - 273;
    counter_lost_can_vehicle = 0;
    break;

  case PGN12:
    data_can.vehicleWeight = (frame.data[1] | frame.data[2] << 8) / 2000.0f;
    counter_lost_can_vehicle = 0;
    break;

  default:
    break;
  }
  portEXIT_CRITICAL(&dataMux);
}

/*
    рассчет уровня экономичного вождения на основе карты ACC\RPM и данных с КАН шины,
    сглаживание результата с помощью фильтра скользящего среднего
*/
int calculation_economical_driving(Can_Data &data)
{
  int map_acc = constrain(data.ACC / 3, 0, COLUM - 1);
  int map_rpm = constrain((data.rpm - 500) / 100, 0, LINE - 1);

  if (data.rpm < 500)
    map_rpm = 0;

  levelEconomicalDriving = constrain((1.0 - K) * levelEconomicalDriving + K * map_ACC_RPM[map_rpm][map_acc], 0.0, 100.0);
  return levelEconomicalDriving;
}

//  рассчет среднего расхода газа на основе данных с КАН шины
float calculation_average_gasconsumption(Can_Data &data)
{
  if (data.distLPG.result == 0)
    return 0;
  return data.cngTripFuel * 100.0 / data.distLPG.result;
}

//  рассчет пробега на запасе газа на основе данных с КАН шины
int calculation_gas_mileage(Can_Data &data)
{
  int res{};
  if (data.average_gasconsumption && data.cngTripFuel)
    res = data.cngLevel * data.tankVolume / (2 * KG_TO_M3 * data.average_gasconsumption);
  else
    res = data.cngLevel * data.tankVolume / (2 * KG_TO_M3 * 20);
  return res;
}

// загрузка карты ACC\RPM из внешнего файла в массив map_ACC_RPM
bool loadAccRpmFile(uint8_t (&map)[LINE][COLUM], const String &name)
{
  const String path = "/" + name;

  if (!LittleFS.exists(path))
  {
    // log_e("Map %s not found", name.c_str());
    return false;
  }

  File file = LittleFS.open(path, FILE_READ);
  if (!file)
  {
    // log_e("Failed to open map %s", name.c_str());
    return false;
  }

  std::vector<String> lines;
  while (file.available())
  {
    String s = file.readStringUntil('\n');
    s.trim();
    if (s.length())
      lines.push_back(s);
  }
  file.close();

  if (lines.empty())
    return false;

  size_t firstMapLine = 0;
  while (firstMapLine < lines.size() && !lines[firstMapLine].startsWith("500"))
    ++firstMapLine;

  if (firstMapLine >= lines.size())
  {
    // log_e("Map data section not found in %s", name.c_str());
    return false;
  }

  memset(map, 0, sizeof(map));
  int row = 0;
  for (size_t k = firstMapLine; k < lines.size() && row < LINE; ++k, ++row)
  {
    const String &s = lines[k];
    int col = 0;
    int start = 0;

    while (start <= s.length() && col < (COLUM + 1))
    {
      int sep = s.indexOf(';', start);
      if (sep < 0)
        sep = s.length();

      String token = s.substring(start, sep);
      token.trim();

      if (col > 0)
      {
        int mapCol = col - 1;
        if (mapCol < COLUM)
          map[row][mapCol] = static_cast<uint8_t>(constrain(token.toInt(), 0, 255));
      }

      ++col;
      start = sep + 1;

      if (sep >= s.length())
        break;
    }
  }

  File src = LittleFS.open(path, FILE_READ);
  if (!src)
    return true;

  src.close();
  return true;
}

/*
    обновление данных для отображения на TFT дисплее,
    расчет уровня экономичного вождения, среднего расхода газа
    и газового пробега на основе данных с КАН шины
*/
void uiTick(void *pvParameters)
{
  for (;;)
  {
    Can_Data loc_canDat{};

    portENTER_CRITICAL(&dataMux);
    loc_canDat = data_can;
    portEXIT_CRITICAL(&dataMux);

    if (gas_on)
    {
      loc_canDat.levelEconomicalDriving = calculation_economical_driving(loc_canDat);

      if (startGas == false)
      {
        loc_canDat.distLPG.begin = loc_canDat.distance;
        loc_canDat.average_gasconsumption = 0.0;
        startGas = true;
      }
      loc_canDat.distLPG.result = loc_canDat.distance - loc_canDat.distLPG.begin;
    }
    else
    {
      loc_canDat.distLPG.begin = loc_canDat.distance;
      startGas = false;
    }

    if (loc_canDat.rpm < 500)
    {
      loc_canDat.distLPG.begin = loc_canDat.distance;
      startGas = false;
    }

    // log_e("Distance: %.2f km, Trip Fuel: %.2f l, Average Gas Consumption: %.2f l/100km, Gas Mileage: %.2f km",
    // loc_canDat.distLPG.result, loc_canDat.cngTripFuel, loc_canDat.average_gasconsumption, loc_canDat.distLPG.gas_mileage);

    if (loc_canDat.distLPG.result > 1.0)
    {
      loc_canDat.average_gasconsumption = calculation_average_gasconsumption(loc_canDat);

      // if (loc_canDat.average_gasconsumption > 25.5)
      // loc_canDat.average_gasconsumption = 25.5;
    }

    loc_canDat.distLPG.gas_mileage = (1 - K) * loc_canDat.distLPG.gas_mileage + K * calculation_gas_mileage(loc_canDat);
    if (loc_canDat.distLPG.gas_mileage > 2550.0)
      loc_canDat.distLPG.gas_mileage = 2550.0;

    portENTER_CRITICAL(&dataMux);
    data_can.levelEconomicalDriving = loc_canDat.levelEconomicalDriving;
    data_can.distLPG.begin = loc_canDat.distLPG.begin;
    data_can.distLPG.result = loc_canDat.distLPG.result;
    data_can.average_gasconsumption = loc_canDat.average_gasconsumption;
    data_can.distLPG.gas_mileage = loc_canDat.distLPG.gas_mileage;
    portEXIT_CRITICAL(&dataMux);

    if (g_displayQueue)
    {
      DisplayMessage msg{};
      msg.type = DisplayCmdType::ShowPage; // обновление данных для отображения на TFT дисплее
      xQueueSend(g_displayQueue, &msg, 0); // только если очередь длиной 1}
    }

    vTaskDelay(pdMS_TO_TICKS(PERIOD_UPDATE_UI));
  }
  vTaskDelete(NULL);
}

// вывод данных на TFT дисплее
void taskDisplay(void *pvParameters)
{
  DisplayMessage msg{};
  Can_Data lastData{};
  int lastPage = 0;
  for (;;)
  {
    if (xQueueReceive(g_displayQueue, &msg, portMAX_DELAY) == pdTRUE)
    {
      switch (msg.type)
      {
      case DisplayCmdType::UpdateData:
        lastData = msg.data;
        maindisplay->setData(lastData, valves);
        break;
      case DisplayCmdType::ShowPage:
        lastPage = msg.page;
        maindisplay->update();
        break;
      case DisplayCmdType::NextPage:
        maindisplay->nextUserPage();
        break;
      case DisplayCmdType::PrevPage:
        maindisplay->prevUserPage();
        break;
      }
    }
  }
  vTaskDelete(NULL);
}

// отправка сообщения в КАН шину
void send_CAN(void *pvParameters)
{
  for (;;)
  {
    Can_Data loc_canDat{};
    bool localCanOk;

    portENTER_CRITICAL(&dataMux);
    loc_canDat = data_can;
    localCanOk = can_ok;
    portEXIT_CRITICAL(&dataMux);

    if (localCanOk && millis() > 10000)
    {
      uint8_t payload[8] = {0};
      payload[0] = loc_canDat.levelEconomicalDriving;
      payload[1] = static_cast<uint8_t>(loc_canDat.average_gasconsumption * 2);
      payload[2] = static_cast<uint8_t>(loc_canDat.distLPG.gas_mileage / 10);
      payload[3] = static_cast<uint8_t>(loc_canDat.tankVolume / 10);

      sendCanFrame(PGN_SEND_DATA, payload, 8, 100);
    }
    vTaskDelay(pdMS_TO_TICKS(500));
  }
  vTaskDelete(NULL);
}

// контроль потери данных с КАН шины
void watch_dog_CAN(void *pvParameters)
{
  for (;;)
  {
    portENTER_CRITICAL(&dataMux);
    counter_lost_can_vehicle++;
    counter_lost_can_EVO++;
    portEXIT_CRITICAL(&dataMux);
    vTaskDelay(pdMS_TO_TICKS(1000));
  }
  vTaskDelete(NULL);
}

// тарирование данных уровня топлива в дизельном баке по данным с датчика LLS
int lls_tarring(int data, int maxVolumeOil, int maxVolumeLLS)
{
  if (data > 4095 || maxVolumeOil == 0 || maxVolumeLLS == 0)
    return -1;
  else 
    return map(data, 1, maxVolumeLLS, 1, maxVolumeOil);
  
  // std::map<int, int> table_taring{{1, 0}, {maxVolume Oil, maxVolumeLLS}};
  // auto iterator = table_taring.begin();

  // if (data > 4095 || maxVolume Oil == 0 || maxVolumeLLS == 0)
  //   return -1;

  // for (int i = 0; i < table_taring.size(); i++)
  // {
  //   if (data > iterator->first)
  //     iterator++;
  //   else
  //   {
  //     auto min = iterator;
  //     iterator++;
  //     auto max = iterator;
  //     return map(data, min->first, max->first, min->second, max->second);
  //   }
  // }
};

// загрузка настроек дисплея в json файл
bool loadDisplayConfig()
{
  File configFile = LittleFS.open("/display_config.json", "r");
  if (!configFile)
  {
    log_i("loadDisplayConfig: file not found");
    return false;
  }

  DynamicJsonDocument doc(1536);
  DeserializationError error = deserializeJson(doc, configFile);
  configFile.close();

  if (error)
  {
    log_i("loadDisplayConfig: json parse failed");
    return false;
  }

  if (doc.containsKey("canSpeed"))
    data_can.canSpeed = doc["canSpeed"].as<int>();

  if (doc.containsKey("vehicleType"))
    data_can.vehicleType = doc["vehicleType"].as<String>();

  if (doc.containsKey("tankVolume"))
    data_can.tankVolume = doc["tankVolume"].as<int>();

  JsonArray pages = doc["pages"].as<JsonArray>();
  if (!pages.isNull())
  {
    for (int i = 0; i < DISPLAY_PAGE_COUNT && i < pages.size(); ++i)
    {
      g_displayConfig.pages[i].enabled = pages[i]["enabled"].as<bool>();
      // g_displayConfig.pages[i].order = pages[i]["order"].as<uint8_t>();
    }
  }

  log_i("loadDisplayConfig: ok");
  return true;
}

// сохранение настроек дисплея в json файл
bool saveDisplayConfig()
{
  DynamicJsonDocument doc(1536);

  doc["canSpeed"] = data_can.canSpeed;
  doc["vehicleType"] = data_can.vehicleType;
  doc["tankVolume"] = data_can.tankVolume;

  JsonArray pages = doc.createNestedArray("pages");

  for (int i = 0; i < DISPLAY_PAGE_COUNT; ++i)
  {
    JsonObject page = pages.createNestedObject();
    page["key"] = g_displayConfig.pages[i].key;
    page["enabled"] = g_displayConfig.pages[i].enabled;
    // page["order"] = g_displayConfig.pages[i].order;

    // log_e("key %s : enable %d", g_displayConfig.pages[i].key, g_displayConfig.pages[i].enabled);
  }

  File configFile = LittleFS.open("/display_config.json", "w");
  if (!configFile)
  {
    // log_e("saveDisplayConfig: open failed");
    return false;
  }

  if (serializeJsonPretty(doc, configFile) == 0)
  {
    // log_e("saveDisplayConfig: write failed");
    configFile.close();
    return false;
  }

  configFile.close();
  // log_e("saveDisplayConfig: ok");
  return true;
}

// загрузка списка ошибок газового блока EVO из внешнего файла в вектор строк ошибок газового блока EVO
void errorStringtoVec(std::vector<String> &error_evo)
{
  String error{};
  File file = LittleFS.open("/" + ERROR_EVO_NEW, FILE_READ);
  std::vector<String> str_err{};

  int i = 0;
  while (file.available())
  {
    String s = file.readStringUntil('\n');
    error_evo.push_back(s);
  }
  file.close();
}

// обновление строки с ошибками газового блока EVO на основе данных из КАН шины и списка ошибок из вектора строк ошибок газового блока EVO
String updateStringError(uint8_t err[], std::vector<String> &error_evo)
{
  String error{};

  for (int i = 0; i < 6; i++)
  {
    uint8_t errEvo = err[i];
    for (int j = 0; j < 8; j++)
    {
      errEvo & 1 ? error += error_evo.at(i * 8 + j).length() ? String(i * 8 + j + 1) + " " + error_evo.at(i * 8 + j) + "<br>" : error_evo.at(i * 8 + j) : error;
      errEvo = errEvo >> 1;
    }
  }
  if (error.length() == 0)
    error = "Ошибок нет";
  return error;
}

//  обновление данных о температуре чипа для контроля теплового состояния устройства
void taskupdateThermalState(void *pvParameters)
{
  DisplayMessage msg{};
  Can_Data lastData{};
  int lastPage = 0;
  for (;;)
  {

    vTaskDelay(pdMS_TO_TICKS(10000));
    float chipTemp = temperatureRead();
    if (chipTemp > 80.0)
    {
      // 1. Уменьшить мощность Wi-Fi
      esp_wifi_set_max_tx_power(40);
      // 2. Реже обновлять данные и отображение на TFT дисплее
      PERIOD_UPDATE_UI = 1000;
      // 3. Уменьшить яркость TFT
      maindisplay->setMaxBrightness(80);
    }
    else if (chipTemp < 65.0)
    {
      // Восстановить нормальные настройки при снижении температуры
      esp_wifi_set_max_tx_power(78);      // Максимальная мощность Wi-Fi
      PERIOD_UPDATE_UI = 300;             // Стандартный период обновления
      maindisplay->setMaxBrightness(150); // Стандартная яркость TFT 
    }
  }
  vTaskDelete(NULL);
}

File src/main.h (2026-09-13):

#pragma once
#include <Arduino.h>
#include <LittleFS.h>
#include <SPI.h>
#include "TFT_240_240.h"
#include <PNGdec.h>
#include <freertos/task.h>
#include <FreeRTOSConfig.h>
#include <WiFi.h>
#include "CST816D.h"
#include "can_settings.h"
#include "WebPortal.h"
#include <SolenoidHealth.h>

#include <ESP32-TWAI-CAN.hpp>
#include <DisplayConfig.h>


Valve valves[4] = {{SolenoidHealth::OK, 0},  
                  {SolenoidHealth::OK, 0},
                  {SolenoidHealth::OK, 0},
                  {SolenoidHealth::OK, 0}}; // массив для хранения состояния клапанов баллонов

#define CAN_RX GPIO_NUM_20
#define CAN_TX GPIO_NUM_21

CanFrame rxFrame;
#define FORMAT_LITTLEFS_IF_FAILED false

#define I2C_SDA GPIO_NUM_4
#define I2C_SCL GPIO_NUM_5
#define TP_INT GPIO_NUM_0
#define TP_RST GPIO_NUM_1

TFT_240_240 *maindisplay = nullptr;
CST816D touch(I2C_SDA, I2C_SCL, TP_RST, TP_INT);
uint8_t gesture;
uint16_t touchX, touchY;

const char *ssid = "DisplayEVO";
const char *password = "00000001";

const char *loginOTA = "ItalGaz";
const char *passwordOTA = "001";

const String VER = "Ver - 3.1 Date - " + String(__DATE__) + "\r";

const float K = 0.2;

const int TIME_READ_CAN = 100;
int PERIOD_UPDATE_UI = 300;
const int TIME_LOST_CAN = 20;
const int PAUSE_TOUCH_ON = 200;

const float KG_TO_M3 = 0.85f;

const int COLUM = 34;                           //  количество столбцов в карте ACC\RPM
const int LINE = 26;                            //  количество строк в карте ACC\RPM

Can_Data data_can{};
CanFrame canFrame{0};                           // структура посылки в кан шину
uint8_t map_ACC_RPM[LINE][COLUM]{};

const String ERROR_EVO_NEW{"Error_EVO_new.csv"};
std::vector<String> error_evo{};

// temperature_sensor_handle_t temp_sensor = NULL;


unsigned long tim = 0;
unsigned long time_touch = 0;

int counter_lost_can_vehicle = 0;
int counter_lost_can_EVO = 0;
bool can_ok = true; // флаг наличия данных по кан
bool gas_on = true; // флаг работы на газе, устанавливается на основе данных с КАН шины, используется для начала отсчета расхода газа в поездке и расчета уровня экономичного вождения
float levelEconomicalDriving = 0; // уровень экономичного вождения, рассчитывается на основе карты ACC\RPM и данных с КАН шины


bool startGas = false; // флаг начала отсчета расхода газа во время движения на газе

// парсинг PGN
void analise_can_id(CanFrame &data);

// вычисление уровня оценки экономичности вождения
int calculation_economical_driving(Can_Data &date);

// вычисление среднего расхода газа в поездке
float calculation_average_gasconsumption(Can_Data &date);

// вычисление оставшегося пробега на газе
int calculation_gas_mileage(Can_Data &date);

// загрузка карты ACC\RPM из внешнего файла в массив map_ACC_RPM
bool loadAccRpmFile(uint8_t (&)[LINE][COLUM], const String &name);

void uiTick(void *pvParameters);
void send_CAN(void *pvParameters);
void watch_dog_CAN(void *pvParameters);
void taskDisplay(void *pvParameters);
void taskupdateThermalState(void *pvParameters);
int lls_tarring(int data, int maxVolumeOil, int maxVolumeLLS);

bool loadDisplayConfig();
bool saveDisplayConfig();

void errorStringtoVec(std::vector<String> &errror_evo);
String updateStringError(uint8_t err[], std::vector<String> &error_evo);

static portMUX_TYPE dataMux = portMUX_INITIALIZER_UNLOCKED;

extern DisplayConfig g_displayConfig;
QueueHandle_t g_displayQueue = nullptr;

enum class DisplayCmdType : uint8_t
{
    UpdateData,
    ShowPage,
    NextPage,
    PrevPage,
    // ForceRefresh
};

struct DisplayMessage
{
    DisplayCmdType type;
    Can_Data data;
    int page;
};

static inline Can_Data snapshotDataCan()
{
  Can_Data copy;
  portENTER_CRITICAL(&dataMux);
  copy = data_can;
  portEXIT_CRITICAL(&dataMux);
  return copy;
}

static inline bool snapshotCanOk()
{
  bool v;
  portENTER_CRITICAL(&dataMux);
  v = can_ok;
  portEXIT_CRITICAL(&dataMux);
  return v;
}

static void sendCanFrame(uint32_t id, const uint8_t *payload, uint8_t len = 8, uint32_t timeout = 100)
{
  CanFrame tx{};
  tx.identifier = id;
  tx.extd = 1;
  tx.data_length_code = (len > 8) ? 8 : len;

  memset(tx.data, 0, sizeof(tx.data));
  if (payload != nullptr)
    memcpy(tx.data, payload, tx.data_length_code);

  ESP32Can.writeFrame(tx, timeout);
}
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

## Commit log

2025-02-23 Исправление вывода на дисплей.
    [main.cpp]
2025-11-04 Убран индикатор уровня
    [5В+CAN_copper_bottom.gbr, 5В+CAN_copper_top.gbr, 5В+CAN_outline.gbr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]
2025-11-04 Удаление дефолтного образа прошивки
2026-03-10 Рабочий вариант 2025
    [Display_240x240 BOM.csv, Map_ACC-RPM.csv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]
2026-03-24 Добавление файла настройки станиц JSON
    [5В+CAN_copper_bottom.gbr, 5В+CAN_copper_top.gbr, 5В+CAN_outline.gbr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]
2026-06-01 Рабочая версия для синей платы
    [partition.csv]
2026-08-04 финальная версия 08.2026. Добавлен Readmy
    [Дисплей 240х240-B_Cu.gbr, Дисплей 240х240-B_Mask.gbr, Дисплей 240х240-B_Paste.gbr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]
2026-09-13 Редактирование схемы и пп
    [Дисплей 240х240.kicad_pcb]
